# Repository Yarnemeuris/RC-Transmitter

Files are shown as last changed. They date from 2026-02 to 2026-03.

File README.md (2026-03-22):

# RC Transmitter

This is an RC Transmitter for controlling things like planes or cars. It's made with a rp2040 microcontroller and a nRf24 ic for the wireless comunication.

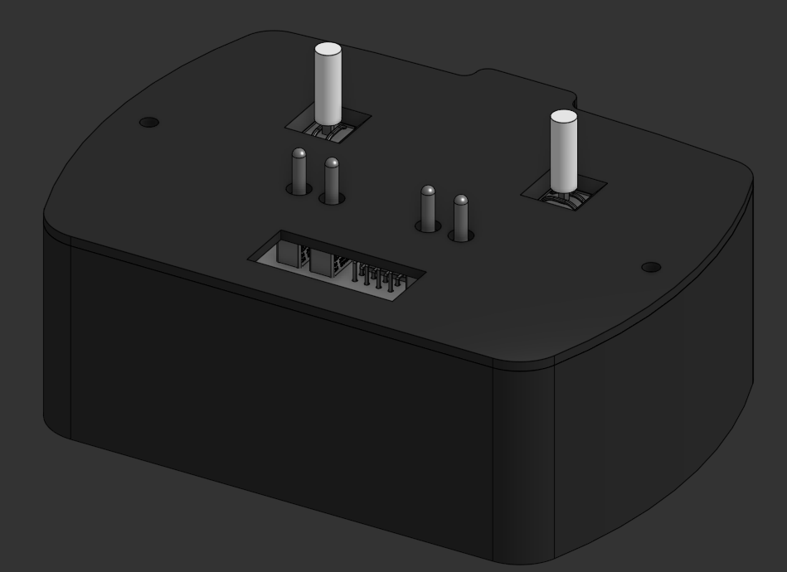
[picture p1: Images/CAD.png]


## CAD
The transmitter is fully 3D printed and uses about 80g of filament. The parts required for assembly are in the BOM. To assemble it you place M3 nuts and add a screw through them. It was fully designed in onshape, so [you can view it](https://cad.onshape.com/documents/07641ffae3f4ad45f3c4466a/w/8f5604270294a6fafcbc2443/e/dfa80ad51705840b5752194c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).

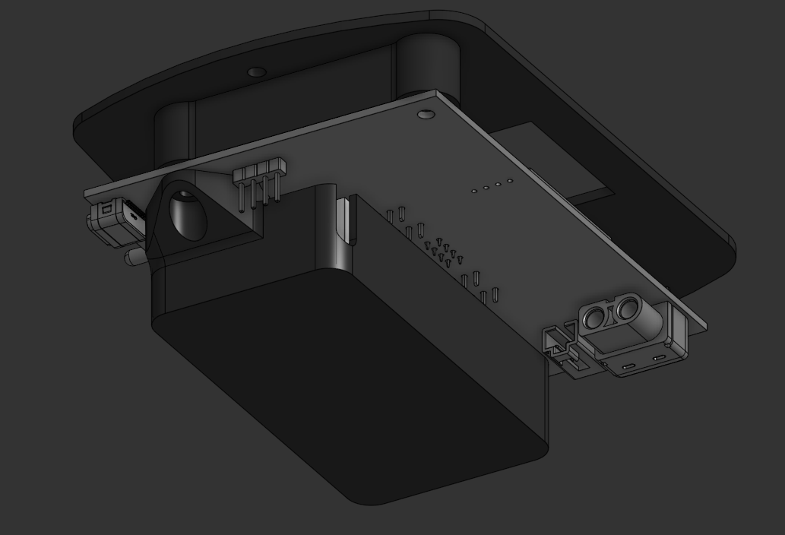
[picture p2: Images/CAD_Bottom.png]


## PCB
In the transmitter are 2 PCBs. One is a 2 layer board for all the wireless things. The same board can be used to recieve the signals, so you need at least 2 of these.

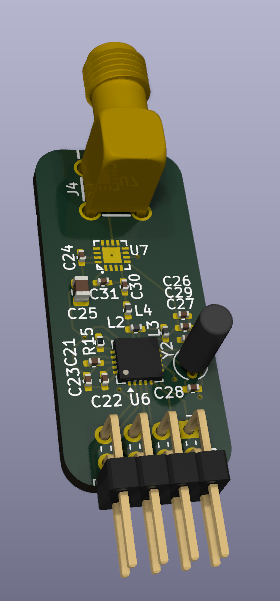
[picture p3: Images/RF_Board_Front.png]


The other one is 4 layers and has everything else on it: the input, microcontroller, battery management. 

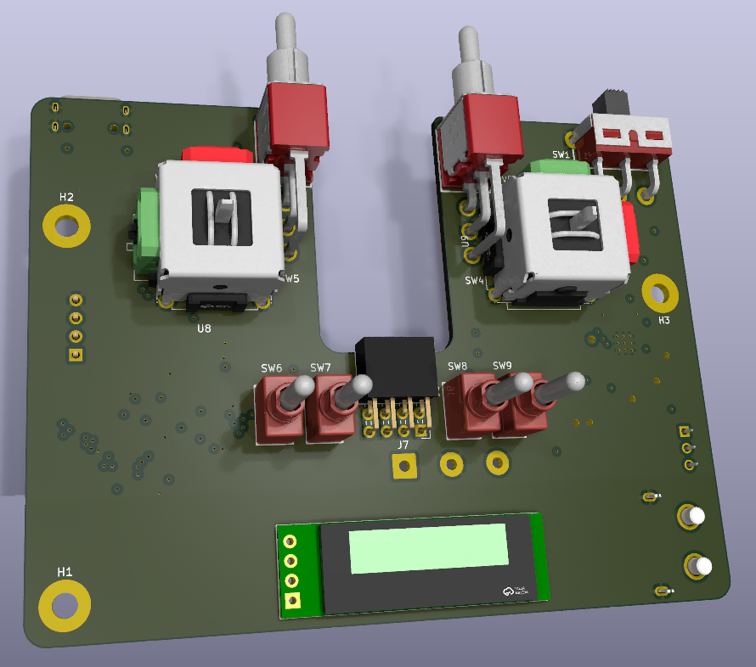
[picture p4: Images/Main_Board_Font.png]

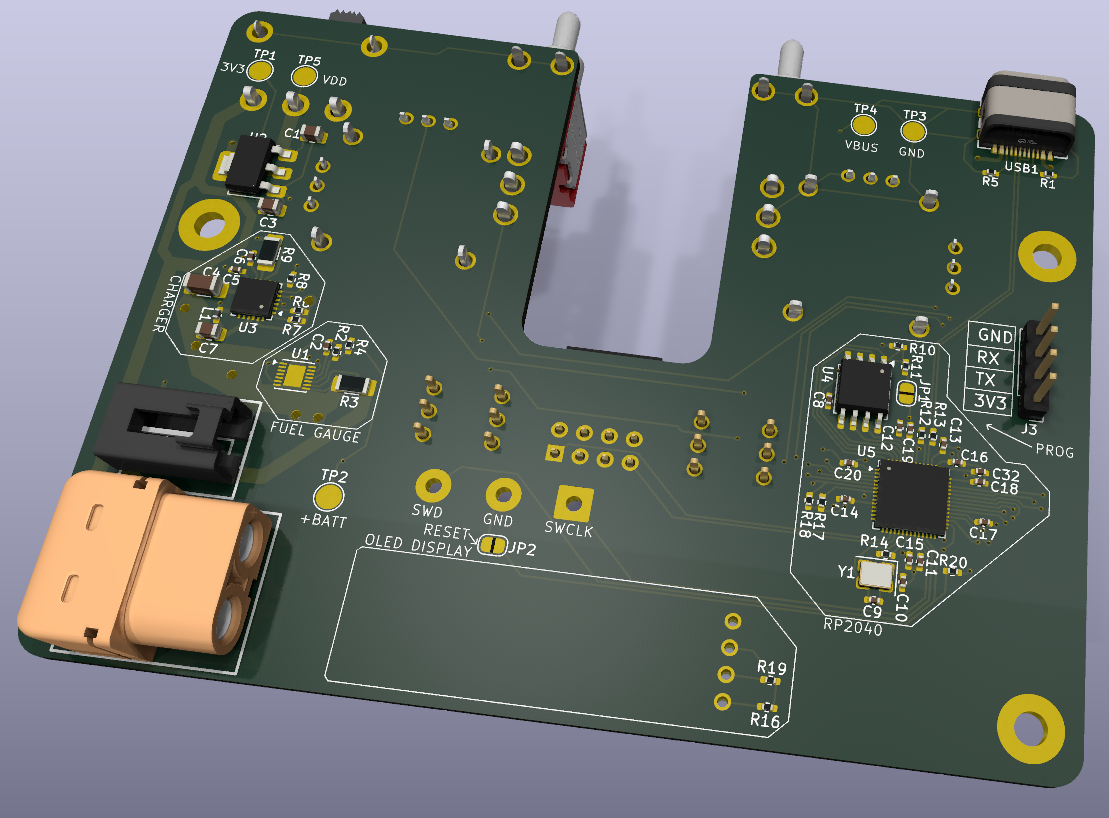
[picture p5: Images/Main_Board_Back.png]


## Firmware
The firmware is setup to transmit everythingvia the second core of the rp2040. This makes sure that it's always available to transmit. The main core does everything else, like drawing to the screen and comunicating with the other ICs. Because this happends on a seperate core, a long I²C message won't stop the transmission. Flashing the board can be done by shorting the two program pads while booting the board, and flashing the [uf2 file](https://github.com/Yarnemeuris/RC-Transmitter/blob/main/Firmware/Firmware.uf2) via the USb connection.

## BOM
This is the simplified BOM. You can find the full and other BOMs [here](https://github.com/Yarnemeuris/RC-Transmitter/tree/main/BOM).

|Category  |Item |Quantity|Unit Price|Total Price|Running Total|
|---|---|---|---|---|---|
|Components|LCSC Components|1 |$43.52 |$43.52 |$43.52 |
|Components|LCSC Shipping  |1 |$11.44 |$11.44 |$54.96 |
|PCB |RF PCB |1 |$2.10 |$2.10 |$57.06 |
|PCB |Main PCB |1 |$7.00 |$7.00 |$64.06 |
|PCB |Stencil |1 |$12.00 |$12.00 |$76.06 |
|PCB |JLCPCB Shipping|1 |$20.15 |$20.15 |$96.21 |

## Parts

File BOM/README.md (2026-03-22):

# BOM

These are the included BOMs:
- Full: Every component needed for a basic setup. (1 Main PCB and 2 RF PCBs)
- Simplified: All the parts from LCSC condensed into one item.
- Main Board: The components from LCSC needed for the Main PCB.
- Rf Board: The components from LCSC needed for one Rf PCB.

If you want BOMs specificly for LCSC/JLCPCB look in [the PCB files](https://github.com/Yarnemeuris/RC-Transmitter/tree/main/PCB/PCBs).

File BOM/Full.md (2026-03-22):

|Category  |Item |Quantity|Minimum Order Quantity|Unit Price|Total Price|URL |Running Total|
|---|---|---|---|---|---|---|---|
|Components|Antenna |2 |1 | $ 0.9257 |$1.85 |https://www.lcsc.com/product-detail/C497017.html  |$1.85 |
|Components|Capacitor 1nF  |2 |100 | $ 0.0011 |$0.11 |https://www.lcsc.com/product-detail/C106205.html  |$1.96 |
|Components|Capacitor 33nF |2 |100 | $ 0.0025 |$0.25 |https://www.lcsc.com/product-detail/C106862.html  |$2.21 |
|Components|Capacitor 10nF |2 |100 | $ 0.0015 |$0.15 |https://www.lcsc.com/product-detail/C15195.html |$2.36 |
|Components|Capacitor 100 nF|13 |100 | $ 0.0013 |$0.13 |https://www.lcsc.com/product-detail/C1525.html |$2.49 |
|Components|Capacitor 10µF |5 |20 | $ 0.0204 |$0.41 |https://www.lcsc.com/product-detail/C15850.html |$2.90 |
|Components|Capacitor 2,2nF|2 |100 | $ 0.0047 |$0.47 |https://www.lcsc.com/product-detail/C126534.html  |$3.37 |
|Components|Capacitor 22pF |6 |20 | $ 0.0203 |$0.41 |https://www.lcsc.com/product-detail/C2176129.html |$3.78 |
|Components|Capacitor 4,7pF|2 |100 | $ 0.0017 |$0.17 |https://www.lcsc.com/product-detail/C189469.html  |$3.95 |
|Components|Capacitor 1,5pF|2 |1 | $ 0.0136 |$0.03 |https://www.lcsc.com/product-detail/C133413.html  |$3.97 |
|Components|Capacitor 1pF  |2 |100 | $ 0.0026 |$0.26 |https://www.lcsc.com/product-detail/C309455.html  |$4.23 |
|Components|Capacitor 1µF  |2 |100 | $ 0.0021 |$0.21 |https://www.lcsc.com/product-detail/C14445.html |$4.44 |
|Components|Capacitor 47µF |1 |1 | $ 0.2644 |$0.26 |https://www.lcsc.com/product-detail/C76659.html |$4.71 |
|Components|Capacitor 47nF |1 |100 | $ 0.0017 |$0.17 |https://www.lcsc.com/product-detail/C285062.html  |$4.88 |
|Components|Capacitor 4,7µF|1 |50 | $ 0.0053 |$0.27 |https://www.lcsc.com/product-detail/C23733.html |$5.14 |
|Components|Inductor 8,2nH |2 |10 | $ 0.0532 |$0.53 |https://www.lcsc.com/product-detail/C98066.html |$5.67 |
|Components|Inductor 2,7nH |2 |10 | $ 0.0400 |$0.40 |https://www.lcsc.com/product-detail/C142181.html  |$6.07 |
|Components|Inductor 3,9nH |2 |1 | $ 0.0191 |$0.04 |https://www.lcsc.com/product-detail/C186820.html  |$6.11 |
|Components|Inductor 1µH |1 |10 | $ 0.0580 |$0.58 |https://www.lcsc.com/product-detail/C531288.html  |$6.69 |
|Components|Resistor 22KΩ  |2 |100 | $ 0.0006 |$0.06 |https://www.lcsc.com/product-detail/C2909337.html |$6.75 |
|Components|Resistor 5,1KΩ |6 |100 | $ 0.0006 |$0.06 |https://www.lcsc.com/product-detail/C2906874.html |$6.81 |
|Components|Resistor 10KΩ  |5 |100 | $ 0.0008 |$0.08 |https://www.lcsc.com/product-detail/C60490.html |$6.89 |
|Components|Resistor 1KΩ |2 |100 | $ 0.0008 |$0.08 |https://www.lcsc.com/product-detail/C106235.html  |$6.97 |
|Components|Resistor 27Ω |2 |100 | $ 0.0008 |$0.08 |https://www.lcsc.com/product-detail/C138021.html  |$7.05 |
|Components|Resistor 200KΩ |1 |100 | $ 0.0008 |$0.08 |https://www.lcsc.com/product-detail/C114763.html  |$7.13 |
|Components|Resistor 10mΩ  |1 |20 | $ 0.0248 |$0.50 |https://www.lcsc.com/product-detail/C7467248.html |$7.63 |
|Components|Resistor 1,3MΩ |1 |50 | $ 0.0060 |$0.30 |https://www.lcsc.com/product-detail/C203121.html  |$7.93 |
|Components|Resistor 300Ω  |1 |100 | $ 0.0026 |$0.26 |https://www.lcsc.com/product-detail/C3013269.html |$8.19 |
|Components|SMA Connector  |2 |1 | $ 0.4986 |$1.00 |https://www.lcsc.com/product-detail/C496551.html  |$9.19 |
|Components|Pin Header |2 |5 | $ 0.0650 |$0.33 |https://www.lcsc.com/product-detail/C7501296.html |$9.51 |
|Components|RF IC |2 |1 | $ 2.4260 |$4.85 |https://www.lcsc.com/product-detail/C8791.html |$14.36 |
|Components|Singal Booster |2 |1 | $ 0.9004 |$1.80 |https://www.lcsc.com/product-detail/C19213.html |$16.16 |
|Components|Crytal 16MHz |2 |5 | $ 0.0790 |$0.40 |https://www.lcsc.com/product-detail/C2836024.html |$16.56 |
|Components|Battery Connector|1 |1 | $ 0.5489 |$0.55 |https://www.lcsc.com/product-detail/C428722.html  |$17.11 |
|Components|battery Balancing Connector|1 |5 | $ 0.0775 |$0.39 |https://www.lcsc.com/product-detail/C704579.html  |$17.49 |
|Components|4 Pin Header |1 |5 | $ 0.0281 |$0.14 |https://www.lcsc.com/product-detail/C32713270.html|$17.64 |
|Components|8 Pin Connector|1 |6 | $ 0.1383 |$0.83 |https://www.lcsc.com/product-detail/C19268754.html|$18.46 |
|Components|OLED Screen |1 |1 | $ 2.1094 |$2.11 |https://www.lcsc.com/product-detail/C5248081.html |$20.57 |
|Components|Power Switch |1 |1 | $ 0.4783 |$0.48 |https://www.lcsc.com/product-detail/C388633.html  |$21.05 |
|Components|Toggle Switch Right Angle|2 |1 | $ 0.8278 |$1.66 |https://www.lcsc.com/product-detail/C1788496.html |$22.71 |
|Components|Toggle Switch  |4 |1 | $ 1.6116 |$6.45 |https://www.lcsc.com/product-detail/C908284.html  |$29.15 |
|Components|Fuel Gauge |1 |1 | $ 5.2813 |$5.28 |https://www.lcsc.com/product-detail/C7457893.html |$34.44 |
|Components|Voltage Regulator|1 |10 | $ 0.0385 |$0.39 |https://www.lcsc.com/product-detail/C347222.html  |$34.82 |
|Components|Battery Charger|1 |1 | $ 2.5071 |$2.51 |https://www.lcsc.com/product-detail/C2761614.html |$37.33 |
|Components|Flash Storage  |1 |1 | $ 2.9654 |$2.97 |https://www.lcsc.com/product-detail/C401671.html  |$40.29 |
|Components|RP2040 |1 |1 | $ 0.9482 |$0.95 |https://www.lcsc.com/product-detail/C2040.html |$41.24 |
|Components|Joystick |1 |1 | $ 0.4843 |$0.48 |https://www.lcsc.com/product-detail/C37323741.html|$41.73 |
|Components|Joystick |1 |1 | $ 0.4224 |$0.42 |https://www.lcsc.com/product-detail/C37323739.html|$42.15 |
|Components|USB-C Port |1 |1 | $ 0.6363 |$0.64 |https://www.lcsc.com/product-detail/C5446865.html |$42.78 |
|Components|Crystal Oscillator|1 |10 | $ 0.0737 |$0.74 |https://www.lcsc.com/product-detail/C9002.html |$43.52 |
|Components|LCSC Shipping  |1 |1 |$11.44 |$11.44 | |$54.96 |
|PCB |RF PCB |1 |1 |$2.10 |$2.10 | |$57.06 |
|PCB |Main PCB |1 |1 |$7.00 |$7.00 | |$64.06 |
|PCB |Stencil |1 |1 |$12.00 |$12.00 | |$76.06 |
|PCB |JLCPCB Shipping|1 |1 |$20.15 |$20.15 | |$96.21 |

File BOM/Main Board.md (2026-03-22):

|Item |Quantity |Minimum Order Quantity|Unit Price|Total Price|URL |Running Total |
|---|---|---|---|---|---|---|
|Capacitor 10µF|3 |10 | $ 0.0723 |$0.72 |https://www.lcsc.com/product-detail/C440198.html|$0.72 |
|Capacitor 22pF|2 |20 | $ 0.0203 |$0.41 |https://www.lcsc.com/product-detail/C2176129.html|$1.13 |
|Capacitor 100nF|11 |100 | $ 0.0013 |$0.13 |https://www.lcsc.com/product-detail/C1525.html|$1.26 |
|Capacitor 1µF|2 |100 | $ 0.0021 |$0.21 |https://www.lcsc.com/product-detail/C14445.html|$1.47 |
|Capacitor 47µF|1 |1 | $ 0.2644 |$0.26 |https://www.lcsc.com/product-detail/C76659.html|$1.73 |
|Capacitor 47nF|1 |100 | $ 0.0017 |$0.17 |https://www.lcsc.com/product-detail/C285062.html|$1.90 |
|Capacitor 4,7µF|1 |50 | $ 0.0053 |$0.27 |https://www.lcsc.com/product-detail/C23733.html|$2.17 |
|Battery Connector|1 |1 | $ 0.5489 |$0.55 |https://www.lcsc.com/product-detail/C428722.html|$2.72 |
|battery Balancing Connector|1 |5 | $ 0.0775 |$0.39 |https://www.lcsc.com/product-detail/C704579.html|$3.10 |
|4 Pin Header|1 |5 | $ 0.0281 |$0.14 |https://www.lcsc.com/product-detail/C32713270.html|$3.25 |
|8 Pin Connector|1 |6 | $ 0.1383 |$0.83 |https://www.lcsc.com/product-detail/C19268754.html|$4.08 |
|Inductor 1µH|1 |10 | $ 0.0580 |$0.58 |https://www.lcsc.com/product-detail/C531288.html|$4.66 |
|OLED Screen|1 |1 | $ 2.1094 |$2.11 |https://www.lcsc.com/product-detail/C5248081.html|$6.76 |
|Resistor 5,1KΩ|6 |100 | $ 0.0006 |$0.06 |https://www.lcsc.com/product-detail/C2906874.html|$6.82 |
|Resistor 10KΩ|5 |100 | $ 0.0008 |$0.08 |https://www.lcsc.com/product-detail/C60490.html|$6.90 |
|Resistor 1KΩ|2 |100 | $ 0.0008 |$0.08 |https://www.lcsc.com/product-detail/C106235.html|$6.98 |
|Resistor 27Ω|2 |100 | $ 0.0008 |$0.08 |https://www.lcsc.com/product-detail/C138021.html|$7.06 |
|Resistor 200KΩ|1 |100 | $ 0.0008 |$0.08 |https://www.lcsc.com/product-detail/C114763.html|$7.14 |
|Resistor 10mΩ|1 |20 | $ 0.0248 |$0.50 |https://www.lcsc.com/product-detail/C7467248.html|$7.64 |
|Resistor 1,3MΩ|1 |50 | $ 0.0060 |$0.30 |https://www.lcsc.com/product-detail/C203121.html|$7.94 |
|Resistor 300Ω|1 |100 | $ 0.0026 |$0.26 |https://www.lcsc.com/product-detail/C3013269.html|$8.20 |
|Power Switch|1 |1 | $ 0.4783 |$0.48 |https://www.lcsc.com/product-detail/C388633.html|$8.68 |
|Toggle Switch Right Angle|2 |1 | $ 0.8278 |$1.66 |https://www.lcsc.com/product-detail/C1788496.html|$10.33 |
|Toggle Switch|4 |1 | $ 1.6116 |$6.45 |https://www.lcsc.com/product-detail/C908284.html|$16.78 |
|Fuel Gauge|1 |1 | $ 5.2813 |$5.28 |https://www.lcsc.com/product-detail/C7457893.html|$22.06 |
|Voltage Regulator|1 |10 | $ 0.0385 |$0.39 |https://www.lcsc.com/product-detail/C347222.html|$22.45 |
|Battery Charger|1 |1 | $ 2.5071 |$2.51 |https://www.lcsc.com/product-detail/C2761614.html|$24.95 |
|Flash Storage|1 |1 | $ 2.9654 |$2.97 |https://www.lcsc.com/product-detail/C401671.html|$27.92 |
|RP2040 |1 |1 | $ 0.9482 |$0.95 |https://www.lcsc.com/product-detail/C2040.html|$28.87 |
|Joystick  |1 |1 | $ 0.4843 |$0.48 |https://www.lcsc.com/product-detail/C37323741.html|$29.35 |
|Joystick  |1 |1 | $ 0.4224 |$0.42 |https://www.lcsc.com/product-detail/C37323739.html|$29.77 |
|USB-C Port|1 |1 | $ 0.6363 |$0.64 |https://www.lcsc.com/product-detail/C5446865.html|$30.41 |
|Crystal Oscillator|1 |10 | $ 0.0737 |$0.74 |https://www.lcsc.com/product-detail/C9002.html|$31.15 |

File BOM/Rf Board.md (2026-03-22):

|Item |Quantity |Minimum Order Quantity|Unit Price|Total Price|URL |Running Total |FIELD8|Amount|
|---|---|---|---|---|---|---|---|---|
|Antenna |1 |1 | $ 0.9257 |$0.93 |https://www.lcsc.com/product-detail/C497017.html|$0.93 | |1 |
|Capacitor 1nF|1 |100 | $ 0.0011 |$0.11 |https://www.lcsc.com/product-detail/C106205.html|$1.04 | | |
|Capacitor 33nF|1 |100 | $ 0.0025 |$0.25 |https://www.lcsc.com/product-detail/C106862.html|$1.29 | | |
|Capacitor 10nF|1 |100 | $ 0.0015 |$0.15 |https://www.lcsc.com/product-detail/C15195.html|$1.44 | | |
|Capacitor 100 nF|1 |100 | $ 0.0013 |$0.13 |https://www.lcsc.com/product-detail/C1525.html|$1.57 | | |
|Capacitor 10µF|1 |20 | $ 0.0204 |$0.41 |https://www.lcsc.com/product-detail/C15850.html|$1.97 | | |
|Capacitor 2,2nF|1 |100 | $ 0.0047 |$0.47 |https://www.lcsc.com/product-detail/C126534.html|$2.44 | | |
|Capacitor 22pF|2 |20 | $ 0.0203 |$0.41 |https://www.lcsc.com/product-detail/C2176129.html|$2.85 | | |
|Capacitor 4,7pF|1 |100 | $ 0.0017 |$0.17 |https://www.lcsc.com/product-detail/C189469.html|$3.02 | | |
|Capacitor 1,5pF|1 |1 | $ 0.0136 |$0.01 |https://www.lcsc.com/product-detail/C133413.html|$3.03 | | |
|Capacitor 1pF|1 |100 | $ 0.0026 |$0.26 |https://www.lcsc.com/product-detail/C309455.html|$3.29 | | |
|SMA Connector|1 |1 | $ 0.4986 |$0.50 |https://www.lcsc.com/product-detail/C496551.html|$3.79 | | |
|Pin Header|1 |5 | $ 0.0650 |$0.33 |https://www.lcsc.com/product-detail/C7501296.html|$4.12 | | |
|Inductor 8,2nH|1 |10 | $ 0.0532 |$0.53 |https://www.lcsc.com/product-detail/C98066.html|$4.65 | | |
|Inductor 2,7nH|1 |10 | $ 0.0400 |$0.40 |https://www.lcsc.com/product-detail/C142181.html|$5.05 | | |
|Inductor 3,9nH|1 |1 | $ 0.0191 |$0.02 |https://www.lcsc.com/product-detail/C186820.html|$5.07 | | |
|Resistor 22KΩ|1 |100 | $ 0.0006 |$0.06 |https://www.lcsc.com/product-detail/C2909337.html|$5.13 | | |
|RF IC |1 |1 | $ 2.4260 |$2.43 |https://www.lcsc.com/product-detail/C8791.html|$7.55 | | |
|Singal Booster|1 |1 | $ 0.9004 |$0.90 |https://www.lcsc.com/product-detail/C19213.html|$8.45 | | |
|Crytal 16MHz|1 |5 | $ 0.0790 |$0.40 |https://www.lcsc.com/product-detail/C2836024.html|$8.85 | | |

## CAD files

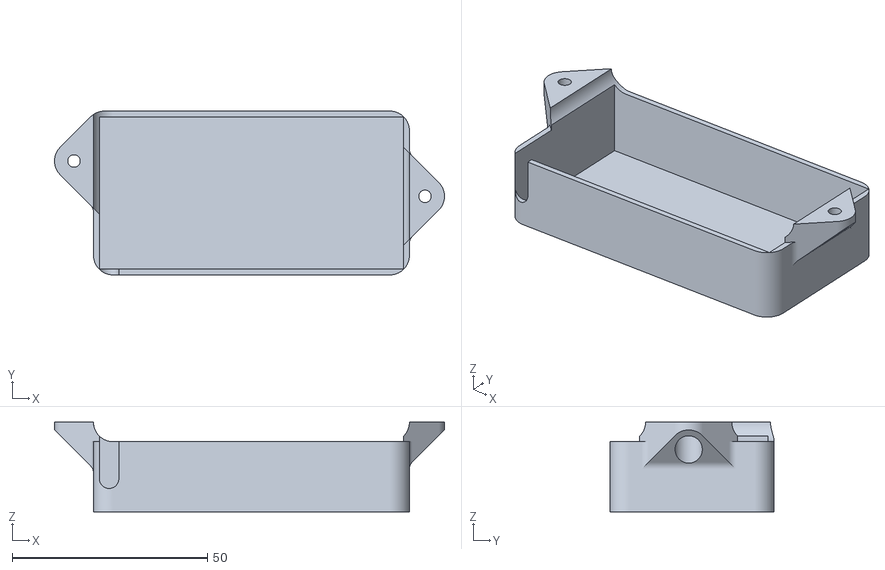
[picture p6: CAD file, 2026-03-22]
CAD/STLs/battery_holder.stl
100.0 x 42.0 x 23.0

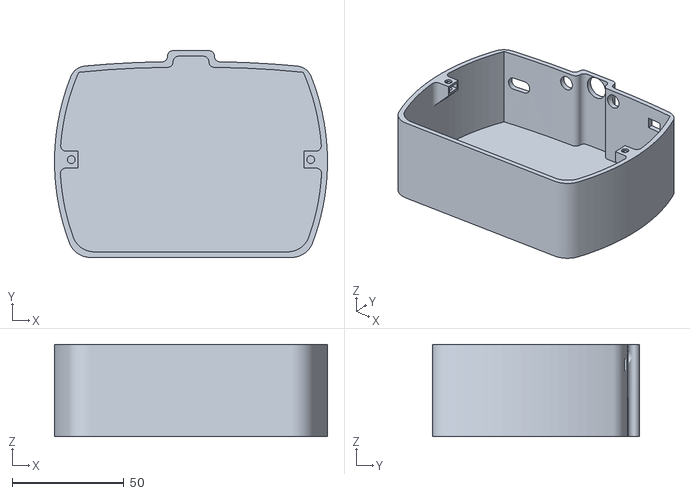
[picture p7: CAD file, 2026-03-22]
CAD/STLs/shell.stl
122.0 x 92.4 x 41.2

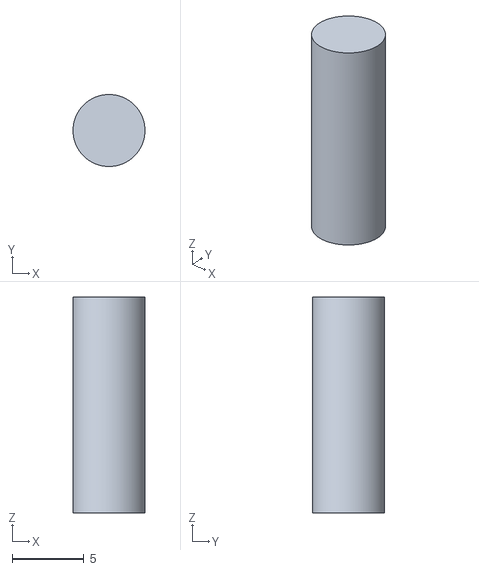
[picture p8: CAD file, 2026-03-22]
CAD/STLs/2x_stick.stl
5.00 x 5.00 x 15.0

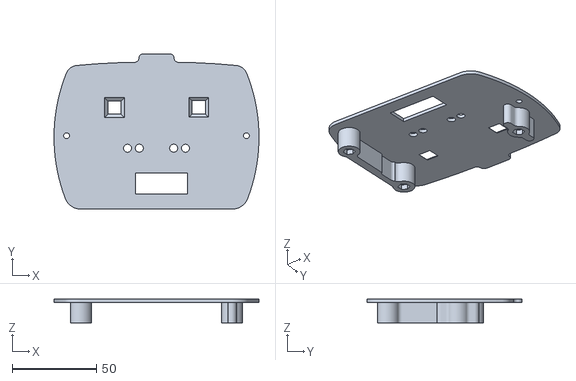
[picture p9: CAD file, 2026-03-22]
CAD/STLs/top.stl
122.0 x 92.4 x 14.2

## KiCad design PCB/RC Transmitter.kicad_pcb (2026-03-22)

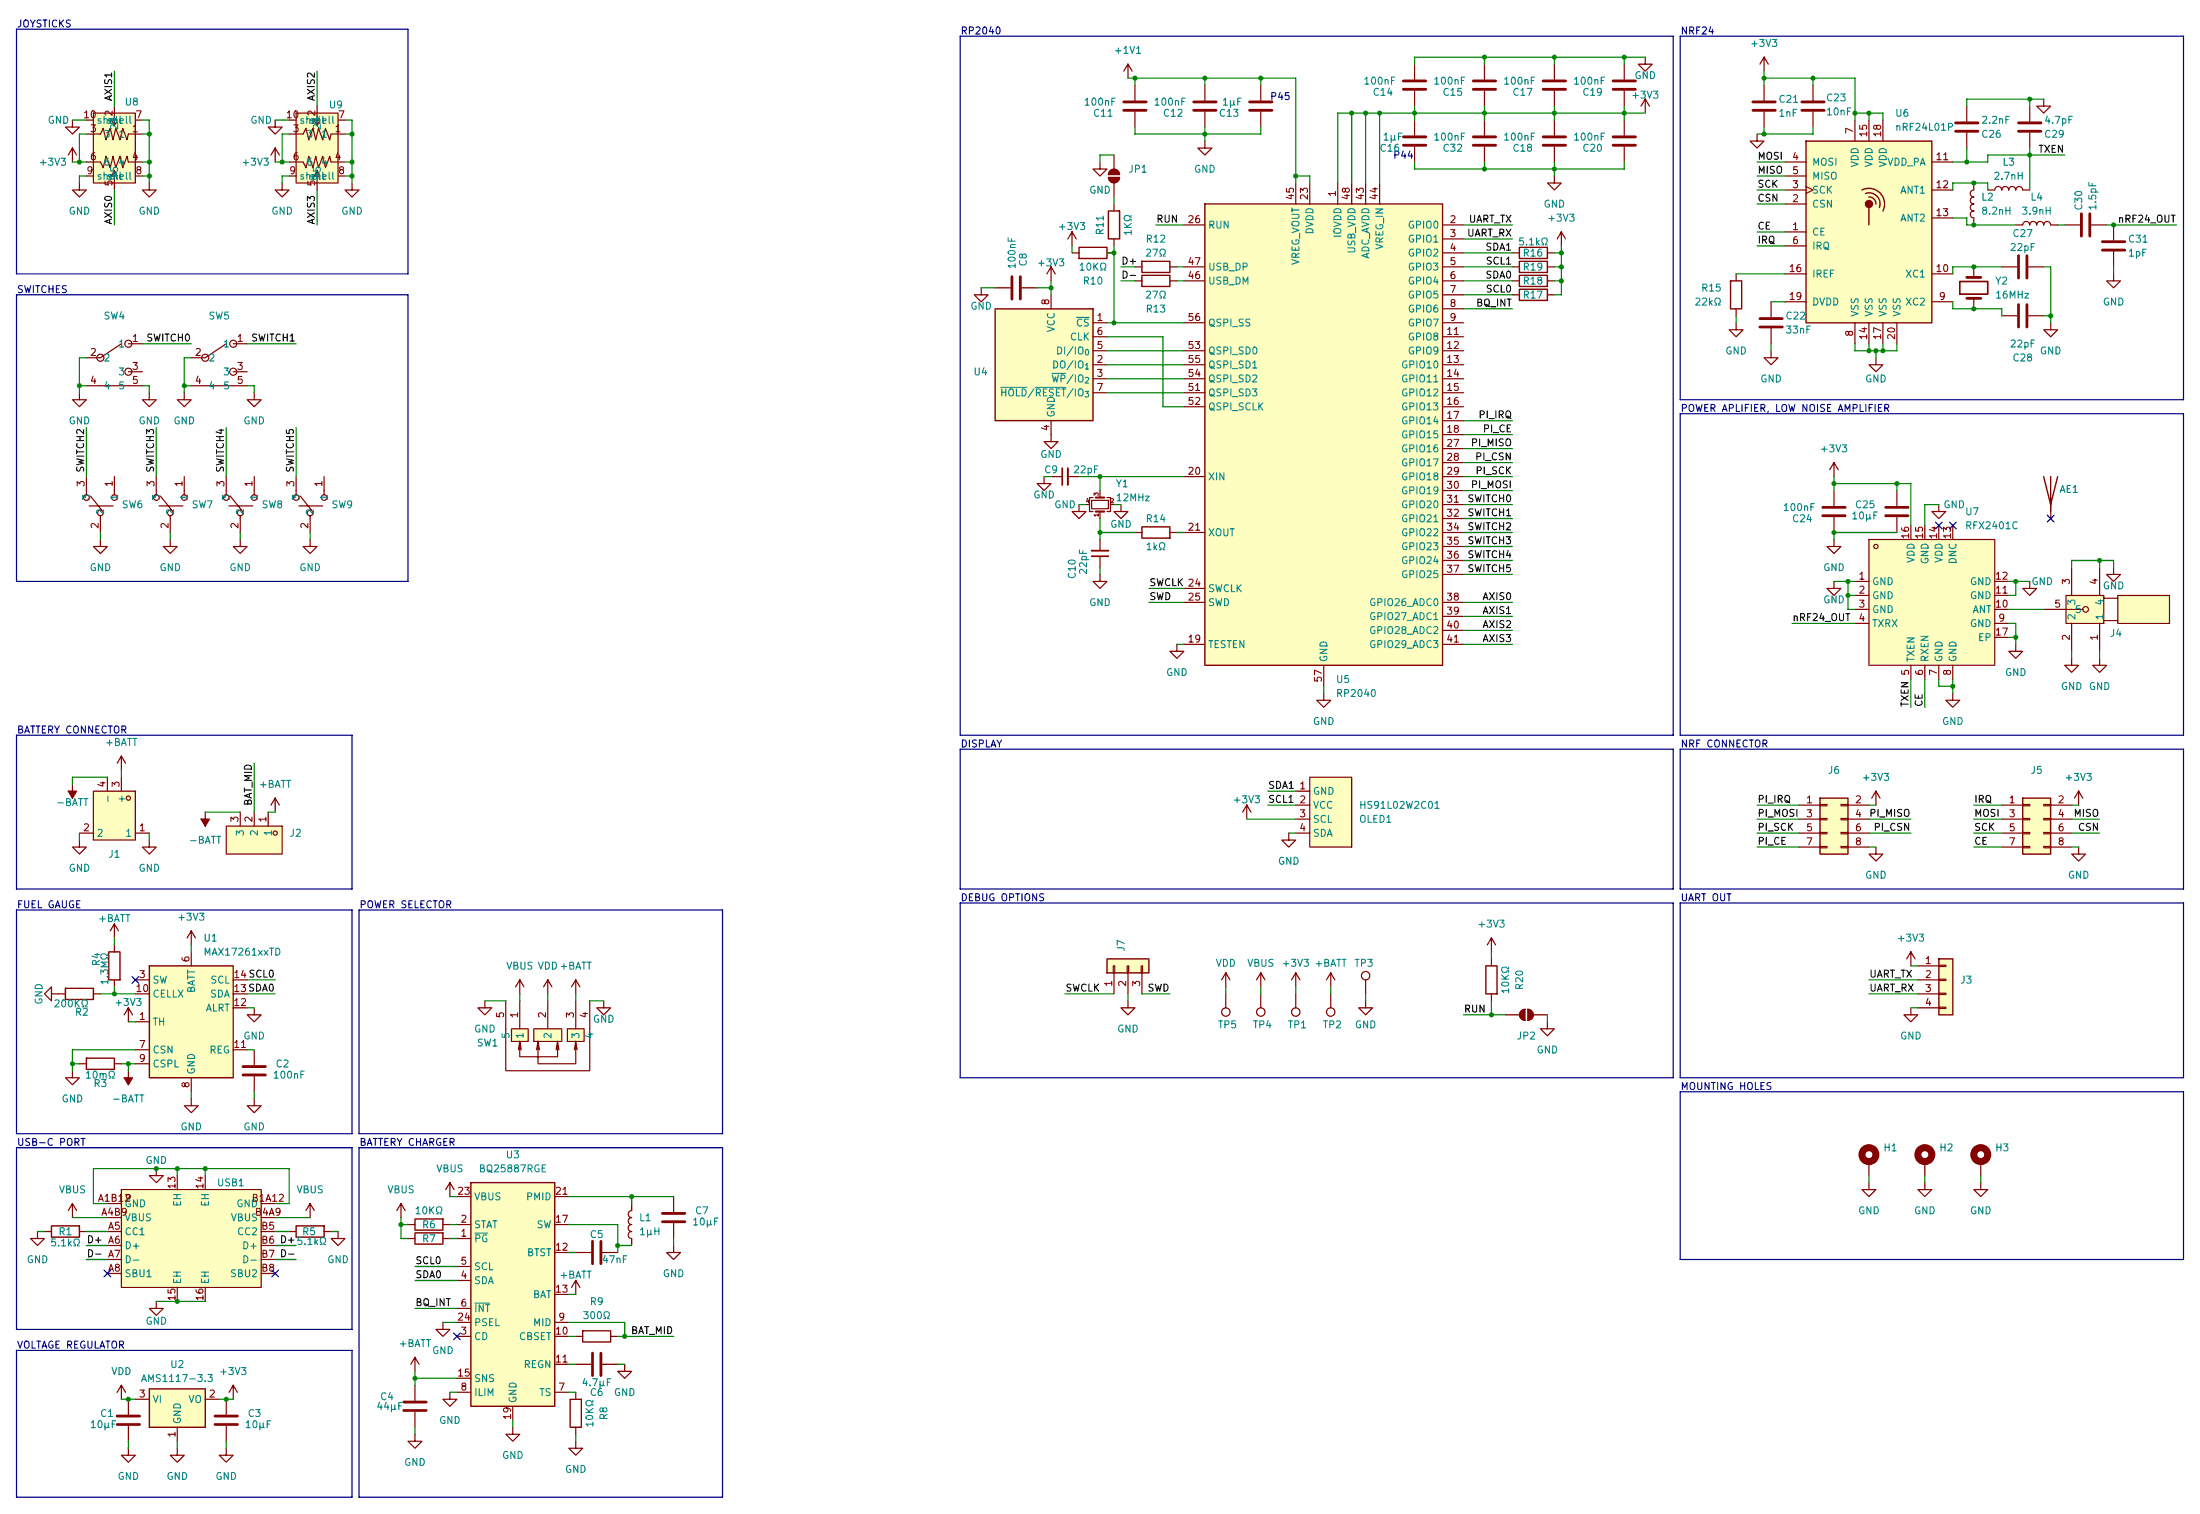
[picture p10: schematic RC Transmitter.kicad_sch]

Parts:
AE1: Antenna; SolderJumper-2_P1.3mm_Bridged2Bar_Pad1.0x1.5mm; LCSC Part C497017
C1, C3, C7, C25: 10µF; C_0805_2012Metric; LCSC Part C15850
C2, C8, C11, C12, C14, C15, C17, C18, C19, C20, C24, C32: 100nF; C_0402_1005Metric_Pad0.74x0.62mm_HandSolder; LCSC Part C1525
C4: 44µF; C_1206_3216Metric_Pad1.33x1.80mm_HandSolder; LCSC Part C76659
C5: 47nF; C_0402_1005Metric_Pad0.74x0.62mm_HandSolder; LCSC Part C285062
C6: 4.7µF; C_0402_1005Metric_Pad0.74x0.62mm_HandSolder; LCSC Part C23733
C9, C10: 22pF; C_0402_1005Metric_Pad0.74x0.62mm_HandSolder; LCSC C2176129
C13, C16: 1µF; C_0402_1005Metric_Pad0.74x0.62mm_HandSolder; LCSC Part C14445
C21: 1nF; C_0402_1005Metric_Pad0.74x0.62mm_HandSolder; LCSC Part C106205
C22: 33nF; C_0402_1005Metric_Pad0.74x0.62mm_HandSolder; LCSC Part C106862
C23: 10nF; C_0402_1005Metric_Pad0.74x0.62mm_HandSolder; LCSC Part C15195
C26: 2.2nF; C_0402_1005Metric_Pad0.74x0.62mm_HandSolder; LCSC Part C126534
C27, C28: 22pF; C_0402_1005Metric_Pad0.74x0.62mm_HandSolder; LCSC Part C2176129
C29: 4.7pF; C_0402_1005Metric_Pad0.74x0.62mm_HandSolder; LCSC Part C189469
C30: 1.5pF; C_0402_1005Metric_Pad0.74x0.62mm_HandSolder; LCSC Part C133413
C31: 1pF; C_0402_1005Metric_Pad0.74x0.62mm_HandSolder; LCSC Part C309455
H1, H2, H3: MountingHole_Pad; MountingHole_3.2mm_M3_Pad
J1: XT60PW-F_C428722; TH_2P-XT60PW-F; LCSC Part C428722
J2: HX25418-3WA; CONN-TH_HX25418-3WA; LCSC Part C704579
J3: Conn_01x04; PinHeader_1x04_P2.54mm_Vertical; LCSC Part C32713270
J4: BWSMA-KWE-Z001; SMA-TH_BWSMA-KWE-Z001; LCSC Part C496551
J5: Conn_02x04_Odd_Even; PinHeader_2x04_P2.54mm_Horizontal; LCSC Part C7501296
J6: Conn_02x04_Odd_Even; PinSocket_2x04_P2.54mm_Horizontal; LCSC Part C19268754
J7: Conn_01x03; SolderWire-0.75sqmm_1x03_P7mm_D1.25mm_OD3.5mm
JP1, JP2: SolderJumper_2_Open; SolderJumper-2_P1.3mm_Open_RoundedPad1.0x1.5mm
L1: 1µH; L_0402_1005Metric_Pad0.77x0.64mm_HandSolder; LCSC Part C531288
L2: 8.2nH; L_0402_1005Metric_Pad0.77x0.64mm_HandSolder; LCSC Part C98066
L3: 2.7nH; L_0402_1005Metric_Pad0.77x0.64mm_HandSolder; LCSC Part C142181
L4: 3.9nH; L_0402_1005Metric_Pad0.77x0.64mm_HandSolder; LCSC Part C186820
OLED1: HS91L02W2C01; OLED-TH_L38.0-W12.0_HS91L02W2C01; LCSC Part C5248081
R1, R5, R16, R17, R18, R19: 5.1kΩ; R_0402_1005Metric_Pad0.72x0.64mm_HandSolder; LCSC C2906874
R2: 200KΩ; R_0402_1005Metric_Pad0.72x0.64mm_HandSolder; LCSC C114763
R3: 10mΩ; R_1206_3216Metric_Pad1.30x1.75mm_HandSolder; LCSC C7467248
R4: 1.3MΩ; R_0402_1005Metric_Pad0.72x0.64mm_HandSolder; LCSC C203121
R6, R7, R8, R10, R20: 10KΩ; R_0402_1005Metric_Pad0.72x0.64mm_HandSolder; LCSC Part C60490
R9: 300Ω; R_1206_3216Metric_Pad1.30x1.75mm_HandSolder; LCSC Part C3013269
R11: 1KΩ; R_0402_1005Metric_Pad0.72x0.64mm_HandSolder; LCSC Part C106235
R12, R13: 27Ω; R_0402_1005Metric_Pad0.72x0.64mm_HandSolder; LCSC Part C138021
R14: 1kΩ; R_0402_1005Metric_Pad0.72x0.64mm_HandSolder; LCSC C106235
R15: 22kΩ; R_0402_1005Metric_Pad0.72x0.64mm_HandSolder; LCSC Part C2909337
SW1: SS-12D11G5R; SW-TH_SS-12D11G5R; LCSC Part C388633
SW4, SW5: MT-0-102-C004-N004-RS; SW-TH_MT-0-102-C004-N004-RS; LCSC Part C1788496
SW6, SW7, SW8, SW9: 2AS3T1A1M2QES; SW-TH_2AS3T1A1M2QES; LCSC Part C908284
TP1, TP2, TP3, TP4, TP5: TestPoint; TestPoint_Pad_D2.5mm
U1: MAX17261xxTD; TDFN-14-1EP_3x3mm_P0.4mm_EP1.78x2.35mm; LCSC Part C7457893
U2: AMS1117-3.3; SOT-223-3_TabPin2; LCSC Part C347222
U3: BQ25887RGE; Texas_RGE0024H_VQFN-24-1EP_4x4mm_P0.5mm_EP2.7x2.7mm_Thermal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; LCSC Part C2761614
U4: W25Q128JVS; SOIC-8_5.3x5.3mm_P1.27mm; LCSC Part C401671
U5: RP2040; QFN-56-1EP_7x7mm_P0.4mm_EP3.2x3.2mm; LCSC Part C2040
U6: nRF24L01P; QFN-20-1EP_4x4mm_P0.5mm_EP2.5x2.5mm; LCSC Part C8791
U7: RFX2401C; QFN-16_L3.0-W3.0-P0.50-BL-EP1.7; LCSC Part C19213
U8: YF16-DFL7.2-B5KO(45-10)B5KO(55)-RG-A22; JOYTICK-TH_YF16-DFL7.2-B5KO-45-10-B5KO-55--RG-A22; LCSC Part C37323741
U9: YF16-FL7.2-B5KA(45-10)-R-A28; JOYTICK-TH_YF16-DFL7.2-B5KO-45-10-B5KO-55--RG-A22; LCSC Part C37323739
USB1: GT-USB-7070A01; USB-SMD_GT-USB-7070A01; LCSC Part C5446865
Y1: 12MHz; Crystal_SMD_3225-4Pin_3.2x2.5mm; LCSC Part C9002
Y2: 16MHz; Crystal_Round_D3.0mm_Vertical; LCSC Part C2836024

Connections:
+1V1: C11.1, C12.1, C13.1, U5.23 (DVDD), U5.45 (VREG_VOUT), U5.50 (DVDD)
+3V3: C3.2, C8.2, C14.2, C15.2, C16.1, C17.2, C18.1, C19.2, C20.1, C21.2, C23.2, C24.1, C25.2, C32.1, J3.1, J5.2, J6.2, OLED1.3 (SCL), R10.2, R16.2, R17.2, R18.2, R19.2, R20.1, TP1.1, U1.1 (TH), U1.6 (BATT), U2.2 (VO), U4.8 (VCC), U5.1 (IOVDD), U5.10 (IOVDD), U5.22 (IOVDD), U5.33 (IOVDD), U5.42 (IOVDD), U5.43 (ADC_AVDD), U5.44 (VREG_IN), U5.48 (USB_VDD), U5.49 (IOVDD), U6.7 (VDD), U6.15 (VDD), U6.18 (VDD), U7.16 (VDD), U8.3, U8.6, U9.3, U9.6
+BATT: C4.2, J1.3 (+), J2.1, R4.1, SW1.3, TP2.1, U3.13 (BAT), U3.14 (BAT), U3.15 (SNS), U3.16 (SNS)
-BATT: J1.4 (-), J2.3, R3.1, U1.9 (CSPL)
/AXIS0: U5.38 (GPIO26_ADC0), U8.5
/AXIS1: U5.39 (GPIO27_ADC1), U8.2
/AXIS2: U5.40 (GPIO28_ADC2), U9.2
/AXIS3: U5.41 (GPIO29_ADC3), U9.5
/BAT_MID: J2.2, R9.1, U3.9 (MID)
/BQ_INT: U3.6 (~INT), U5.8 (GPIO6)
/CE: J5.7, U6.1 (CE), U7.6 (RXEN)
/CSN: J5.6, U6.2 (CSN)
/D+: R12.2, USB1.A6 (D+), USB1.B6 (D+)
/D-: R13.2, USB1.A7 (D-), USB1.B7 (D-)
/IRQ: J5.1, U6.6 (IRQ)
/MISO: J5.4, U6.5 (MISO)
/MOSI: J5.3, U6.4 (MOSI)
/PI_CE: J6.7, U5.18 (GPIO15)
/PI_CSN: J6.6, U5.28 (GPIO17)
/PI_IRQ: J6.1, U5.17 (GPIO14)
/PI_MISO: J6.4, U5.27 (GPIO16)
/PI_MOSI: J6.3, U5.30 (GPIO19)
/PI_SCK: J6.5, U5.29 (GPIO18)
/RUN: JP2.1 (A), R20.2, U5.26 (RUN)
/SCK: J5.5, U6.3 (SCK)
/SCL0: R17.1, U1.14 (SCL), U3.5 (SCL), U5.7 (GPIO5)
/SCL1: OLED1.2 (VCC), R19.1, U5.5 (GPIO3)
/SDA0: R18.1, U1.13 (SDA), U3.4 (SDA), U5.6 (GPIO4)
/SDA1: OLED1.1 (GND), R16.1, U5.4 (GPIO2)
/SWCLK: J7.1, U5.24 (SWCLK)
/SWD: J7.3, U5.25 (SWD)
/SWITCH0: SW4.1, U5.31 (GPIO20)
/SWITCH1: SW5.1, U5.32 (GPIO21)
/SWITCH2: SW6.3, U5.34 (GPIO22)
/SWITCH3: SW7.3, U5.35 (GPIO23)
/SWITCH4: SW8.3, U5.36 (GPIO24)
/SWITCH5: SW9.3, U5.37 (GPIO25)
/TXEN: C26.2, C29.2, L3.2, U6.11 (VDD_PA), U7.5 (TXEN)
/UART_RX: J3.3, U5.3 (GPIO1)
/UART_TX: J3.2, U5.2 (GPIO0)
/nRF24_OUT: C30.1, C31.2, U7.4 (TXRX)
GND: C1.1, C2.1, C3.1, C4.1, C6.1, C7.1, C8.1, C9.1, C10.1, C11.2, C12.2, C13.2, C14.1, C15.1, C16.2, C17.1, C18.2, C19.1, C20.2, C21.1, C22.1, C23.1, C24.2, C25.1, C26.1, C27.2, C28.2, C29.1, C31.1, C32.2, H1.1, H2.1, H3.1, J1.1, J1.2, J3.4, J4.1, J4.2, J4.3, J4.4, J5.8, J6.8, J7.2, JP1.1 (A), JP2.2 (B), OLED1.4 (SDA), R1.1, R2.2, R3.2, R5.2, R8.1, R15.1, SW1.4, SW1.5, SW4.2, SW4.4, SW4.5, SW5.2, SW5.4, SW5.5, SW6.2, SW7.2, SW8.2, SW9.2, TP3.1, U1.7 (CSN), U1.8 (GND), U1.12 (ALRT), U1.15 (GND), U2.1 (GND), U3.8 (ILIM), U3.19 (GND), U3.20 (GND), U3.24 (PSEL), U3.25 (GND), U4.4 (GND), U5.19 (TESTEN), U5.57 (GND), U6.8 (VSS), U6.14 (VSS), U6.17 (VSS), U6.20 (VSS), U6.21 (EP), U7.1 (GND), U7.2 (GND), U7.3 (GND), U7.7 (GND), U7.8 (GND), U7.9 (GND), U7.11 (GND), U7.12 (GND), U7.15 (GND), U7.17 (EP), U8.1, U8.4, U8.7 (shell), U8.8 (shell), U8.9 (shell), U8.10 (shell), U9.1, U9.4, U9.7 (shell), U9.8 (shell), U9.9 (shell), U9.10 (shell), USB1.13 (EH), USB1.14 (EH), USB1.15 (EH), USB1.16 (EH), USB1.A1B12 (GND), USB1.B1A12 (GND), Y1.2, Y1.4
unnamed: C5.2, L1.1, U3.17 (SW), U3.18 (SW)
unnamed: C7.2, L1.2, U3.21 (PMID), U3.22 (PMID)
unnamed: C10.2, R14.1, Y1.1
unnamed: C30.2, L4.2
unnamed: JP1.2 (B), R11.2
unnamed: R2.1, R4.2, U1.10 (CELLX)
unnamed: C2.2, U1.11 (REG)
unnamed: C5.1, U3.12 (BTST)
unnamed: R9.2, U3.10 (CBSET)
unnamed: C6.2, U3.11 (REGN)
unnamed: R6.2, U3.2 (STAT)
unnamed: R8.2, U3.7 (TS)
unnamed: R7.2, U3.1 (~PG)
unnamed: U4.6 (CLK), U5.52 (QSPI_SCLK)
unnamed: U4.5 (DI/IO_{0}), U5.53 (QSPI_SD0)
unnamed: U4.2 (DO/IO_{1}), U5.55 (QSPI_SD1)
unnamed: R10.1, R11.1, U4.1 (~CS), U5.56 (QSPI_SS)
unnamed: U4.7 (~HOLD/~RESET/IO_{3}), U5.51 (QSPI_SD3)
unnamed: U4.3 (~WP/IO_{2}), U5.54 (QSPI_SD2)
unnamed: R13.1, U5.46 (USB_DM)
unnamed: R12.1, U5.47 (USB_DP)
unnamed: C9.2, U5.20 (XIN), Y1.3
unnamed: R14.2, U5.21 (XOUT)
unnamed: L2.2, L3.1, U6.12 (ANT1)
unnamed: L2.1, L4.1, U6.13 (ANT2)
unnamed: C22.2, U6.19 (DVDD)
unnamed: R15.2, U6.16 (IREF)
unnamed: C27.1, U6.10 (XC1), Y2.2
unnamed: C28.1, U6.9 (XC2), Y2.1
unnamed: J4.5, U7.10 (ANT)
unnamed: R1.2, USB1.A5 (CC1)
unnamed: R5.1, USB1.B5 (CC2)
VBUS: R6.1, R7.1, SW1.1, TP4.1, U3.23 (VBUS), USB1.A4B9 (VBUS), USB1.B4A9 (VBUS)
VDD: C1.2, SW1.2, TP5.1, U2.3 (VI)

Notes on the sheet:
P45
POWER APLIFIER, LOW NOISE AMPLIFIER
NRF24
USB-C PORT
BATTERY CONNECTOR
VOLTAGE REGULATOR
JOYSTICKS
DEBUG OPTIONS
RP2040
POWER SELECTOR
MOUNTING HOLES
NRF CONNECTOR
BATTERY CHARGER
P44
DISPLAY
UART OUT
FUEL GAUGE
SWITCHES

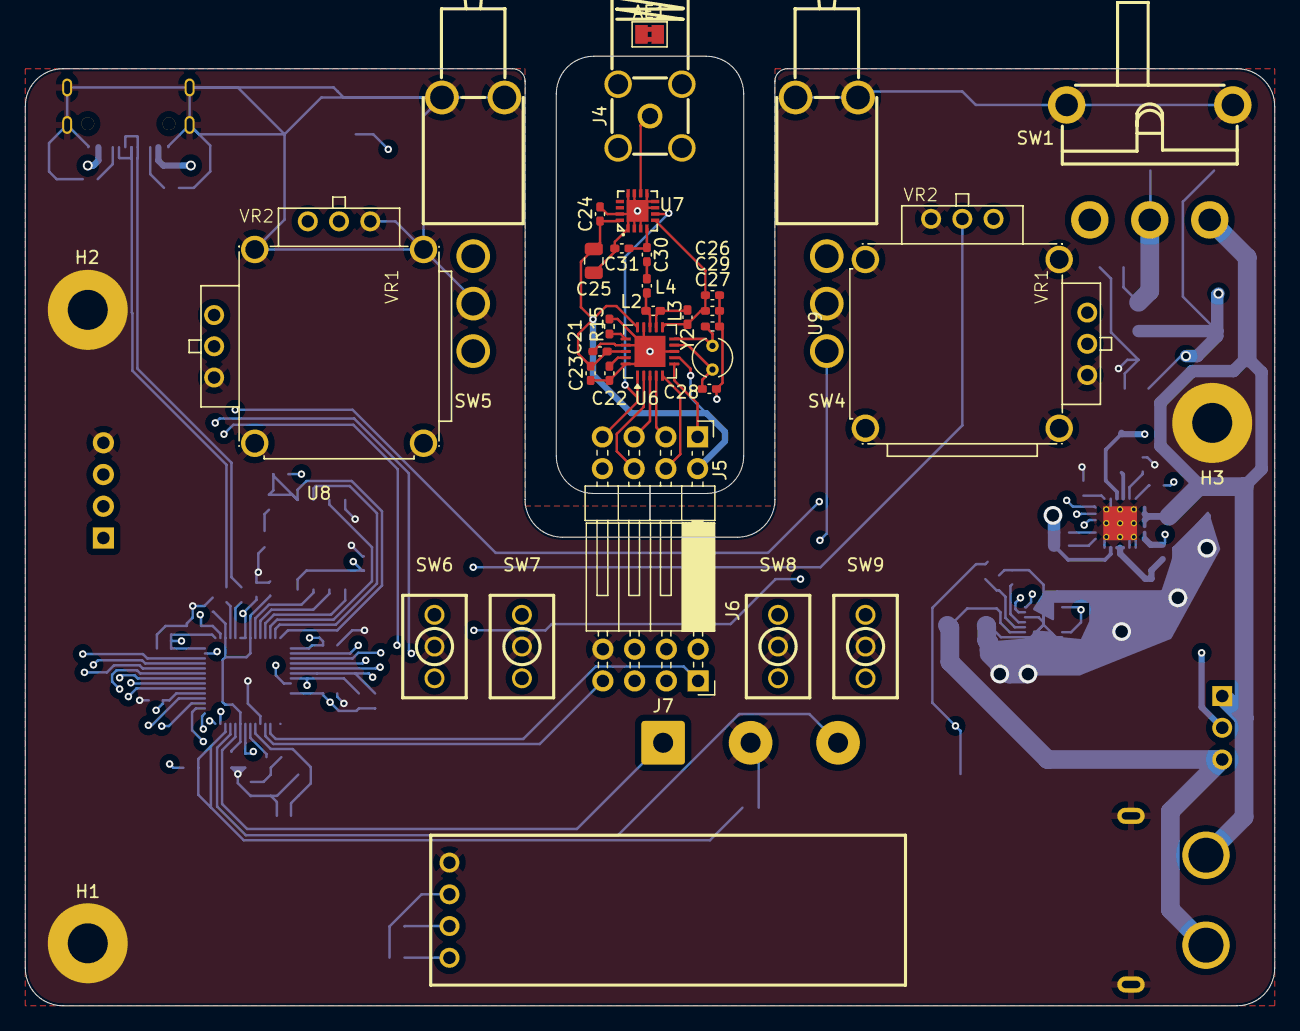
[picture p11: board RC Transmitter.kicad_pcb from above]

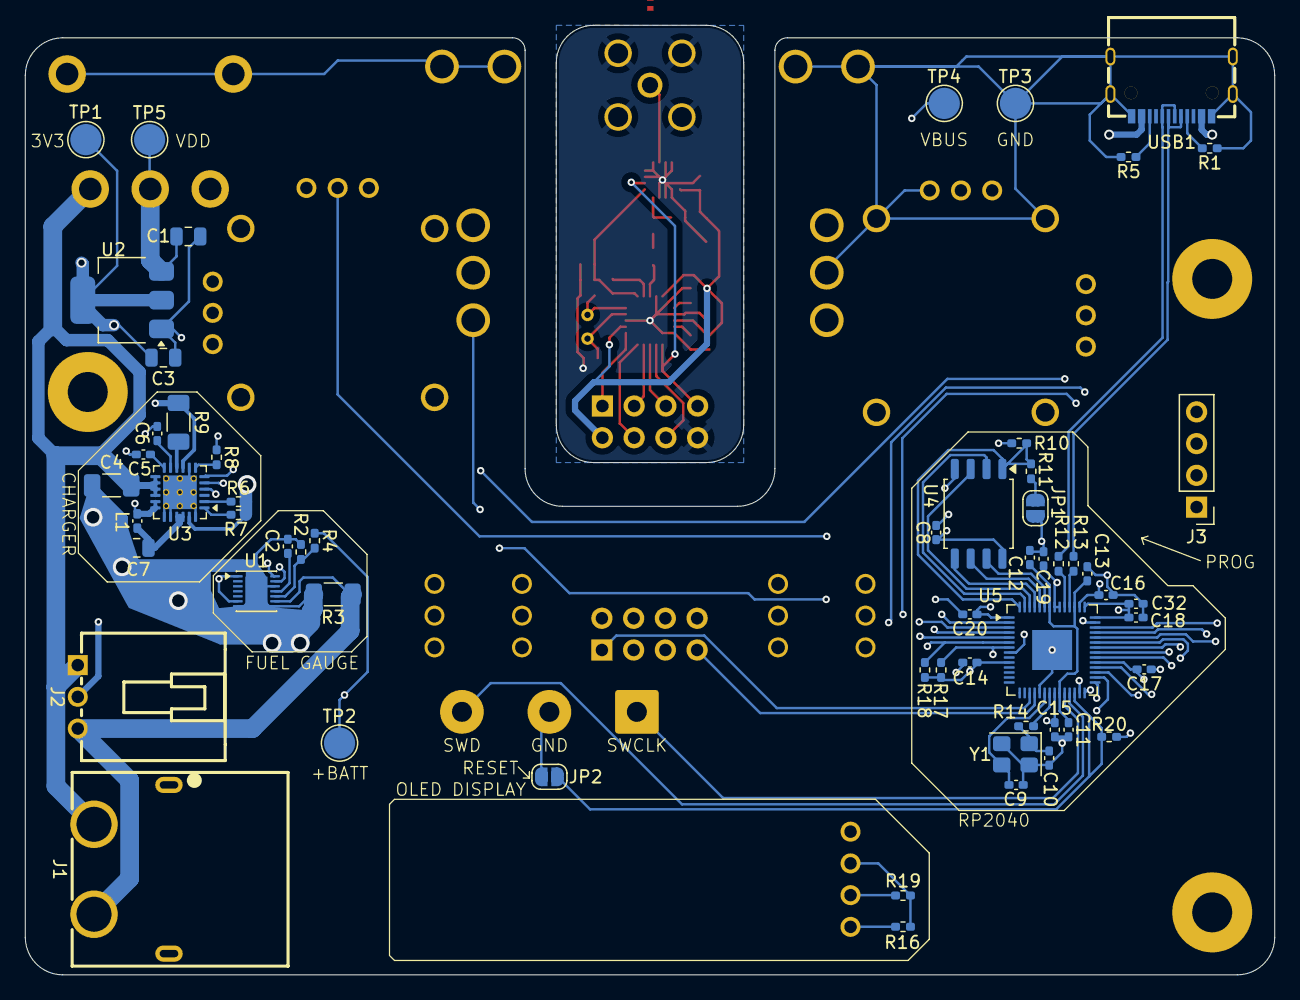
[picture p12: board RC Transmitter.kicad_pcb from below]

Board: 4 copper layers, 100.0 x 76.0 mm, 94 parts (58 on the bottom side), 76 nets.

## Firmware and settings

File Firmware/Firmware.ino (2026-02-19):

#include <SPI.h>
#include "RF24.h"
#include <Wire.h>

#define CE_PIN 15
#define CSN_PIN 17

#define updateFreq 50
#define displayFreq 15

#define millisPerUpdate floor(1000 / updateFreq)
#define millisPerDisplay floor(1000 / displayFreq)

uint64_t nextDraw = millis();

void setup() {
  setupBattery(); //start MAX ic and let it get a clear first reading without too much going on

  rp2040.fifo.push(0); //signal CORE1 to start up

  setupDisplay();
}

void loop() {
  if (millis() > nextDraw) {
    nextDraw = millis() + millisPerDisplay;
    updateDisplay();
  }
}

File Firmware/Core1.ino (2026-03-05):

const uint8_t RXAddress[] = "RCT";
const uint8_t TXAdress[] = "1RX";

const uint8_t buttons[6] = { 20, 21, 22, 23, 24, 25 };
const uint8_t axes[4] = { 26, 27, 28, 29 };

uint8_t invertButtons = 0b0000000;                                                //set to 1 to invert button
uint8_t axesSetinngs[4][2] = { { 0, 100 }, { 0, 100 }, { 0, 100 }, { 0, 100 } };  //first expo 0-100 then rate 0-100

uint64_t nextUpdate = millis();

struct stateStruct {
  int16_t axes[4];
  uint8_t buttons;
};

struct payloadStruct {
  struct stateStruct state;
};

stateStruct* sharedState = new stateStruct;  //create a state object on the heap so it's shared between the cores.

RF24 radio(CE_PIN, CSN_PIN);

void setup1() {
  while (rp2040.fifo.available() == 0) delay(10);  //wait until core0 wants to start the second core
  rp2040.fifo.pop();

  setupInputs();
  setupRF24();

  *sharedState = getState();  //set initial values for the shared state
}

void loop1() {
  if (millis() > nextUpdate) {
    nextUpdate = millis() + millisPerUpdate;
    update();
  }
}

void update() {
  struct stateStruct currentState = getState();
  struct payloadStruct payload = { currentState };

  sendPayload(payload);

  *sharedState = currentState;
}

void setupInputs() {
  for (uint8_t button : buttons) {
    pinMode(button, INPUT_PULLUP);
  }

  for (uint8_t axis : axes) {
    pinMode(axis, INPUT);
  }

  analogReadResolution(12);
}

void setupRF24() {
  SPI.setMISO(16);
  SPI.setCS(17);
  SPI.setSCK(18);
  SPI.setMOSI(19);
  SPI.begin();

  if (!radio.begin(&SPI)) {
    Serial.println(F("radio hardware not responding!!"));
    while (1) {}
  }

  radio.setChannel(100);                        //sets to 2.41 GHZ which is outside of bluethoot and wifi range
  radio.setRetries(5, 2);                       //limits the amount of resends so it doesn't take too long
  radio.setAddressWidth(3);                     //use 3 byte addresses which is the smallest
  radio.setDataRate(RF24_250KBPS);              //slowest data rate for longest range
  radio.setPayloadSize(sizeof(payloadStruct));  //set the payload size to make transmission faster

  radio.stopListening(TXAdress);        //set the adress to transmit to
  radio.openReadingPipe(1, RXAddress);  //set the adress to read ACK from or that's how I think it works
}

bool sendPayload(struct payloadStruct payload) {
  bool report = radio.write(&payload, sizeof(payload));
  return report;
}

struct stateStruct getState() {
  struct stateStruct currentState;

  for (uint8_t i = 0; i < sizeof(axes) / sizeof(axes[0]); i++) {
    currentState.axes[i] = map(analogRead(axes[i]), 0, 4096, -2048, 2048);
  }

  for (uint8_t i = 0; i < sizeof(buttons) / sizeof(buttons[0]); i++) {
    bitWrite(currentState.buttons, i, digitalRead(buttons[i]));
  }

  return currentState;
}

struct stateStruct processState(struct stateStruct state) {
  state.buttons ^= invertButtons;  // XOR to invert buttons

  for (uint8_t i = 0; i < 4; i++) {
    float start = state.axes[i] / 2048.0;
    float expo = axesSetinngs[i][0] / 100.0;
    float rate = axesSetinngs[i][1] / 100.0;
    float edited = ((1-expo)*start + expo * std::pow(start, 3)) * rate;
    state.axes[i] = edited*2048;
  }

  return state;
}

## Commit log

2026-02-14 made the PCB
    [RC Transmitter.kicad_pcb, RC Transmitter.kicad_sch, nRF board.csv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]
2026-02-18 PCB update see journal for more information
    [RC Transmitter.kicad_pcb, RC Transmitter.kicad_sch]
2026-03-05 PCB upadte
    [RC Transmitter.kicad_pcb, RC Transmitter.kicad_sch]
2026-03-22 Changed repo layout
    [2x_stick.stl, Main_Board_Bom.csv, Main_Board_Positions.csv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]
2026-03-22 Added BOMs
    [Full.csv, Main Board.csv, Rf Board.csv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]
2026-03-22 Add links in README
    Updated image references and added links for firmware and BOM.
2026-03-22 Added link to PCB files
2026-03-22 CAD changes
    [battery_holder.stl]
